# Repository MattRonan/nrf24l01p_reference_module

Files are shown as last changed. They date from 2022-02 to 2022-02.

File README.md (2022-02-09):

# nrf24l01p_reference_module
nrf24l01+ board and schematic in Eagle, based on official reference board

nrfbrd

The nrf24l01+ is cheap, well documented, and easy to use, but is way less available than it was a few years ago. I made this based on Nordic's reference module so that  
I wouldnt have to rely on amazon or ali baba suppliers in the future.  The Nordic PDF has extra info about component selection and related things, and is on their website at https://www.nordicsemi.com/Products/nRF24-series

The pdf that this board is based off of is under nRF24Files/nRF24L01P-EK/Documentation/nRF24L01pluss_REFERENCE_MODULES

There are improvements that can be made, most of all shrinking the antenna size down to match typical nrf modules but this is a good starting point

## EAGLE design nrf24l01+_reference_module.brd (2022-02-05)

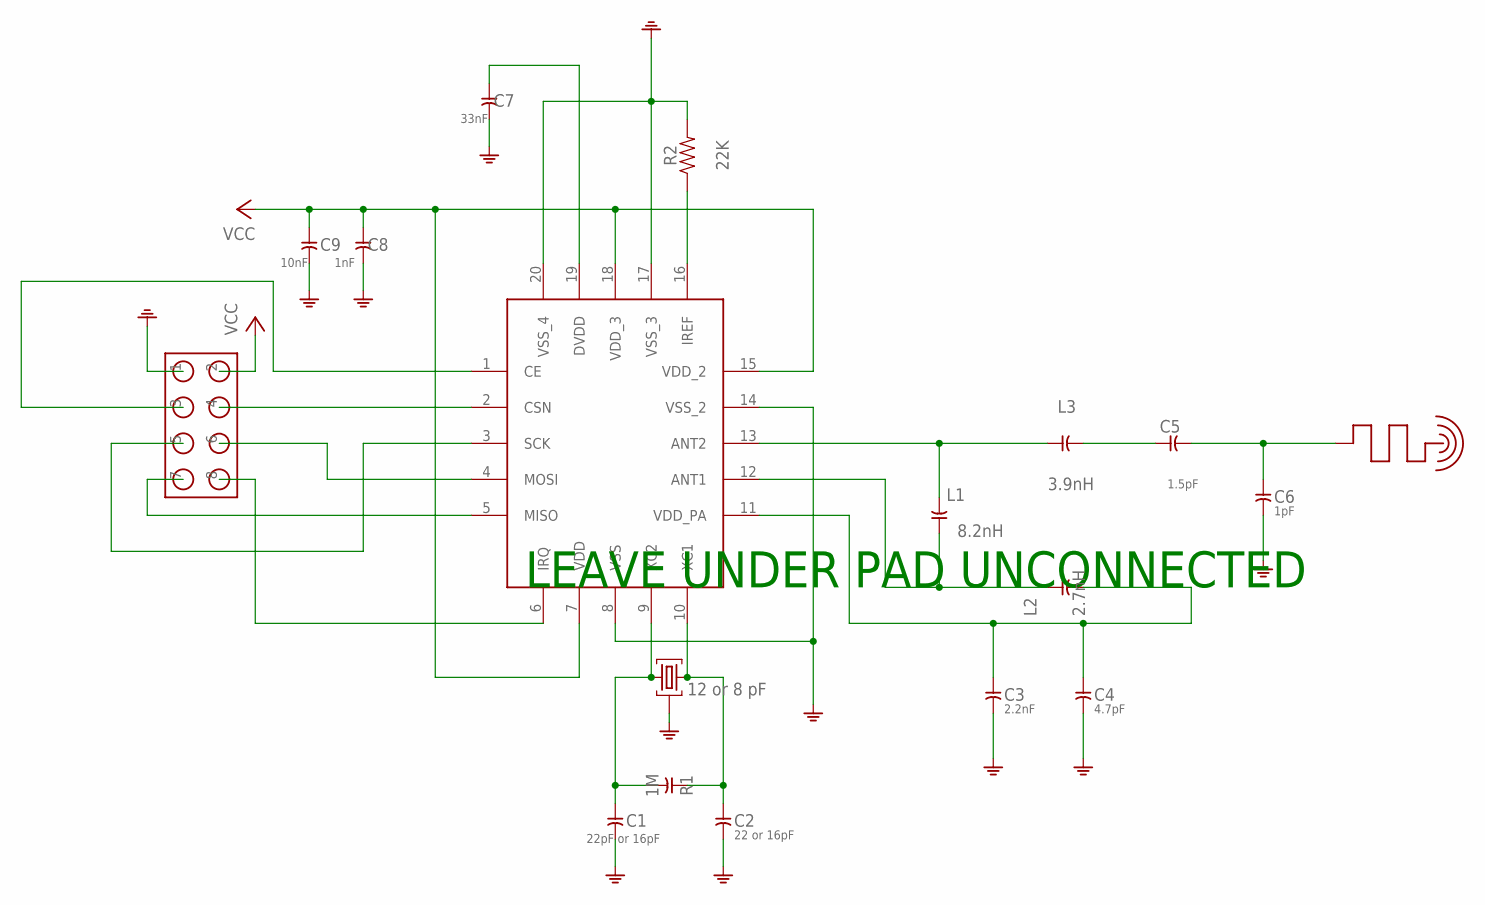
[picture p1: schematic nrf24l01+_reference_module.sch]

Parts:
C1: 22pF or 16pF; 0402_ULTRA_COMPACT
C2: 22 or 16pF; 0402_ULTRA_COMPACT
C3: 2.2nF; 0402_ULTRA_COMPACT
C4: 4.7pF; 0402_ULTRA_COMPACT
C5: 1.5pF; 0402_ULTRA_COMPACT
C6: 1pF; 0402_ULTRA_COMPACT
C7: 33nF; 0402_ULTRA_COMPACT
C8: 1nF; 0402_ULTRA_COMPACT
C9: 10nF; 0402_ULTRA_COMPACT
L1: 8.2nH; 0402_ULTRA_COMPACT
L2: 2.7nH; 0402_ULTRA_COMPACT
L3: 3.9nH; 0402_ULTRA_COMPACT
R1: 1M; 0402_ULTRA_COMPACT
R2: 22K; 0402_COMPACT
U$1: NRF24L01+_NO_UNDERSIDE_PAD; QFN20_4MM_NO_BOTTOM_PAD
U$2: HEADER_2X4; 2X4_2.54MM
U$4: 12 or 8 pF; CRYSTAL_SMD4_PINT_SIZE
U$5: ANTENNA_NRF_REFERENCE_MODULE

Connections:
GND: C1.2, C2.2, C3.2, C4.2, C6.2, C7.2, C8.2, C9.2, R2.2, U$1.8 (VSS), U$1.14 (VSS_2), U$1.17 (VSS_3), U$1.20 (VSS_4), U$2.1, U$4.2(GND) (GND), U$4.4(GND) (GND)
unnamed: U$1.1 (CE), U$2.3
unnamed: U$1.2 (CSN), U$2.4
unnamed: U$1.3 (SCK), U$2.5
unnamed: U$1.4 (MOSI), U$2.6
unnamed: U$1.5 (MISO), U$2.7
unnamed: U$1.6 (IRQ), U$2.8
unnamed: C1.1, R1.2, U$1.9 (XC2), U$4.1
unnamed: C2.1, R1.1, U$1.10 (XC1), U$4.3
unnamed: C7.1, U$1.19 (DVDD)
unnamed: L1.2, L3.1, U$1.13 (ANT2)
unnamed: R2.1, U$1.16 (IREF)
unnamed: L1.1, L2.1, U$1.12 (ANT1)
unnamed: C3.1, C4.1, L2.2, U$1.11 (VDD_PA)
unnamed: C5.1, L3.2
unnamed: C5.2, C6.1, U$5.P$1
VCC: C8.1, C9.1, U$1.7 (VDD), U$1.15 (VDD_2), U$1.18 (VDD_3), U$2.2

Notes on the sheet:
LEAVE UNDER PAD UNCONNECTED

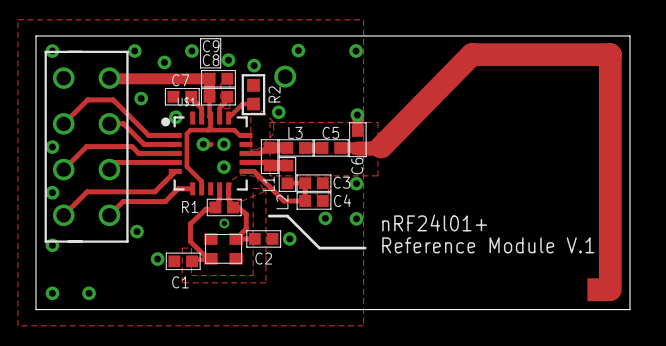
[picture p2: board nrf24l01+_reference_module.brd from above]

Board: 2 copper layers, 33.0 x 15.2 mm, 18 parts (0 on the bottom side), 17 nets.
